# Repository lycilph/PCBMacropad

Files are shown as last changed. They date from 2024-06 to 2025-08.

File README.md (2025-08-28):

# PCBMacropad

Arduino pro micro pinout
* https://learn.sparkfun.com/tutorials/pro-micro--fio-v3-hookup-guide/hardware-overview-pro-micro
 
Kicad resources (for keyboards)
* https://github.com/joe-scotto/scottokeebs/tree/main/Extras/ScottoKicad
* https://github.com/ebastler/marbastlib

Tap drill chart (for self tapping screws into pla)
* https://mae.ufl.edu/designlab/Lab%20Assignments/EML2322L%20Tap%20Drill%20Chart.pdf
* From here: https://www.reddit.com/r/3dprinter/comments/fnlmps/hole_size_for_selftapping_screws/

Keycaps
* https://www.printables.com/model/109679-cherry-mx-low-profile-keycap
* https://www.thingiverse.com/thing:4186055
* https://www.printables.com/model/405230-blank-xda-keycap-mx-compatible
* https://www.printables.com/model/397962-blank-xda-profile-keycaps?ref=makerluis.com

Arduino simulator
* https://wokwi.com/projects/new/arduino-uno
* https://app.cirkitdesigner.com/

Idea for v2:
* https://github.com/dekuNukem/duckyPad-Pro

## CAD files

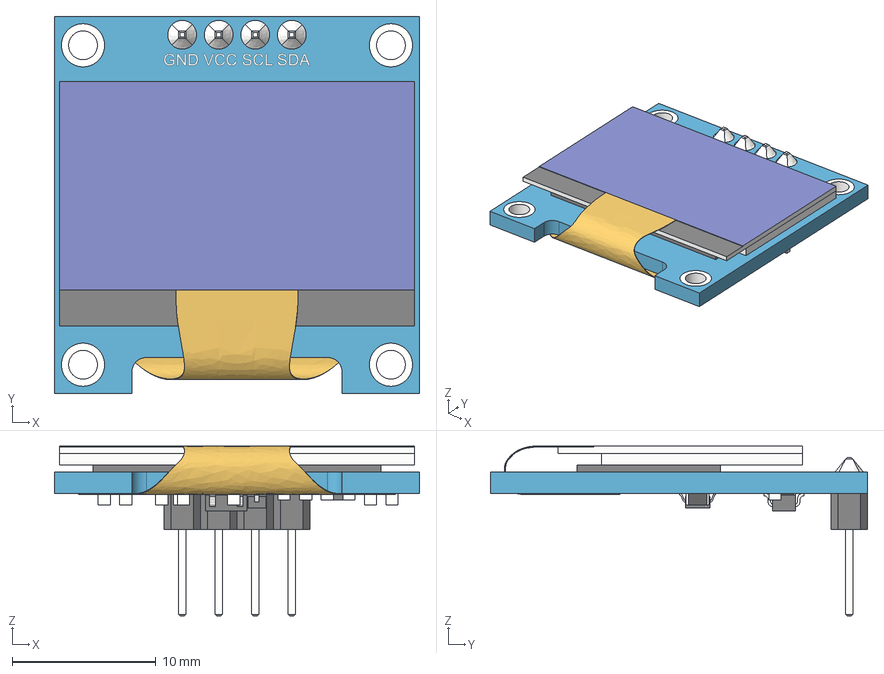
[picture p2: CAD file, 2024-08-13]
pcb_macropad/3dmodels/SSD1306_OLED_Display(128x64).step
25.4 x 26.2 x 11.8 mm
board
screen
pin_header
soldering
smd_capacitor
smd_capacitor (1)
914_smd_resistor
472_smd_resistor x 3
t4_smd_diode
smd_capacitor (2)
smd_capacitor (3)
smd_capacitor (4)
smd_capacitor (5)
smd_capacitor (6)
472_smd_resistor (1)
SOT-23_XC6206 v3
smd_capacitor (7)
flat_cable

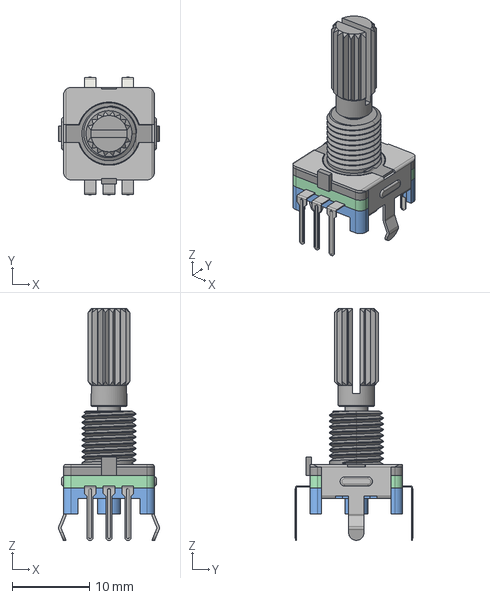
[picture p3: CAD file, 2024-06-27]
pcb_macropad/3dmodels/EC11_Rotary_Encoder_Switched.step
13.1 x 15.3 x 30.1 mm

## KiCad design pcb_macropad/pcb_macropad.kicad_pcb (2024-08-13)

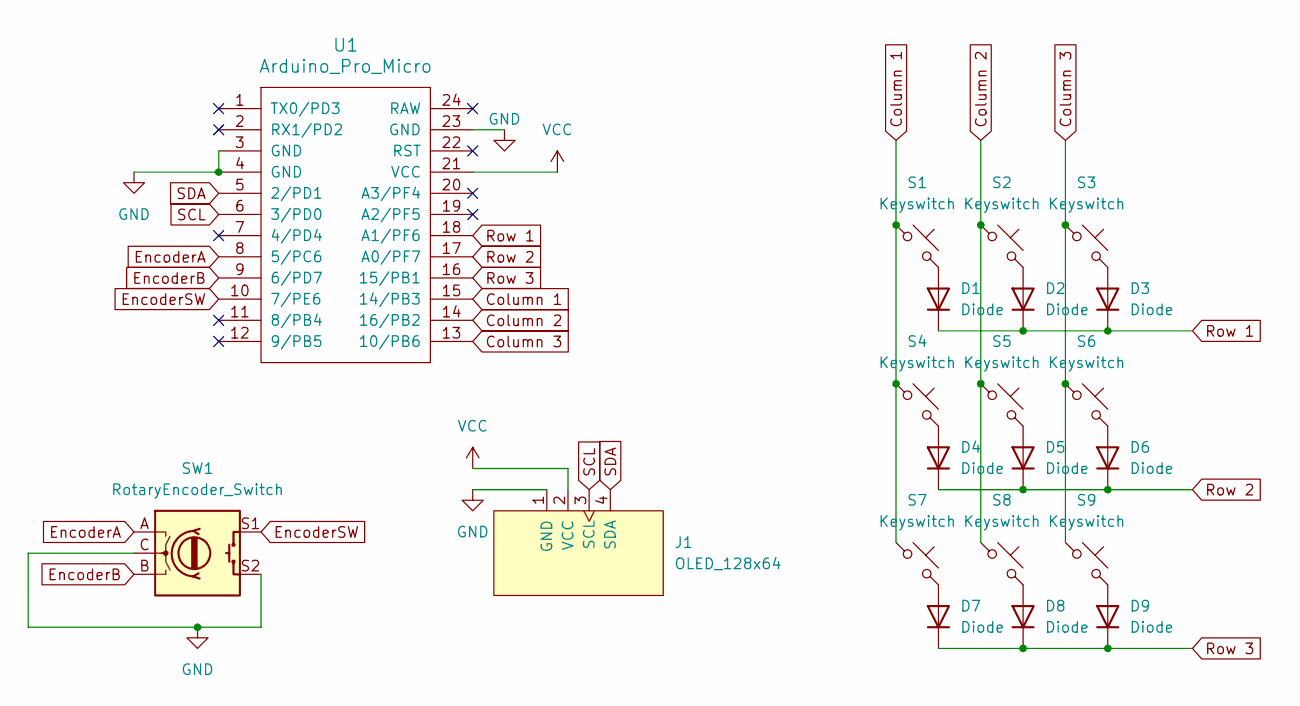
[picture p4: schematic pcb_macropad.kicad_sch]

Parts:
D1, D2, D3, D4, D5, D6, D7, D8, D9: Diode; Diode_DO-35
J1: OLED_128x64; 128x64OLED
S1, S2, S3, S4, S5, S6, S7, S8, S9: Keyswitch; MX_PCB_1.00u
SW1: RotaryEncoder_Switch; RotaryEncoder_Alps_EC11E-Switch_Vertical_H20mm
U1: Arduino_Pro_Micro

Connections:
Column 1: S1.1, S4.1, S7.1, U1.15 (14/PB3)
Column 2: S2.1, S5.1, S8.1, U1.14 (16/PB2)
Column 3: S3.1, S6.1, S9.1, U1.13 (10/PB6)
EncoderA: SW1.A, U1.8 (5/PC6)
EncoderB: SW1.B, U1.9 (6/PD7)
EncoderSW: SW1.S1, U1.10 (7/PE6)
GND: J1.1 (GND), SW1.C, SW1.S2, U1.3 (GND), U1.4 (GND), U1.23 (GND)
unnamed: D1.2 (A), S1.2
unnamed: D2.2 (A), S2.2
unnamed: D3.2 (A), S3.2
unnamed: D4.2 (A), S4.2
unnamed: D5.2 (A), S5.2
unnamed: D6.2 (A), S6.2
unnamed: D7.2 (A), S7.2
unnamed: D8.2 (A), S8.2
unnamed: D9.2 (A), S9.2
Row 1: D1.1 (K), D2.1 (K), D3.1 (K), U1.18 (A1/PF6)
Row 2: D4.1 (K), D5.1 (K), D6.1 (K), U1.17 (A0/PF7)
Row 3: D7.1 (K), D8.1 (K), D9.1 (K), U1.16 (15/PB1)
SCL: J1.3 (SCL), U1.6 (3/PD0)
SDA: J1.4 (SDA), U1.5 (2/PD1)
VCC: J1.2 (VCC), U1.21 (VCC)

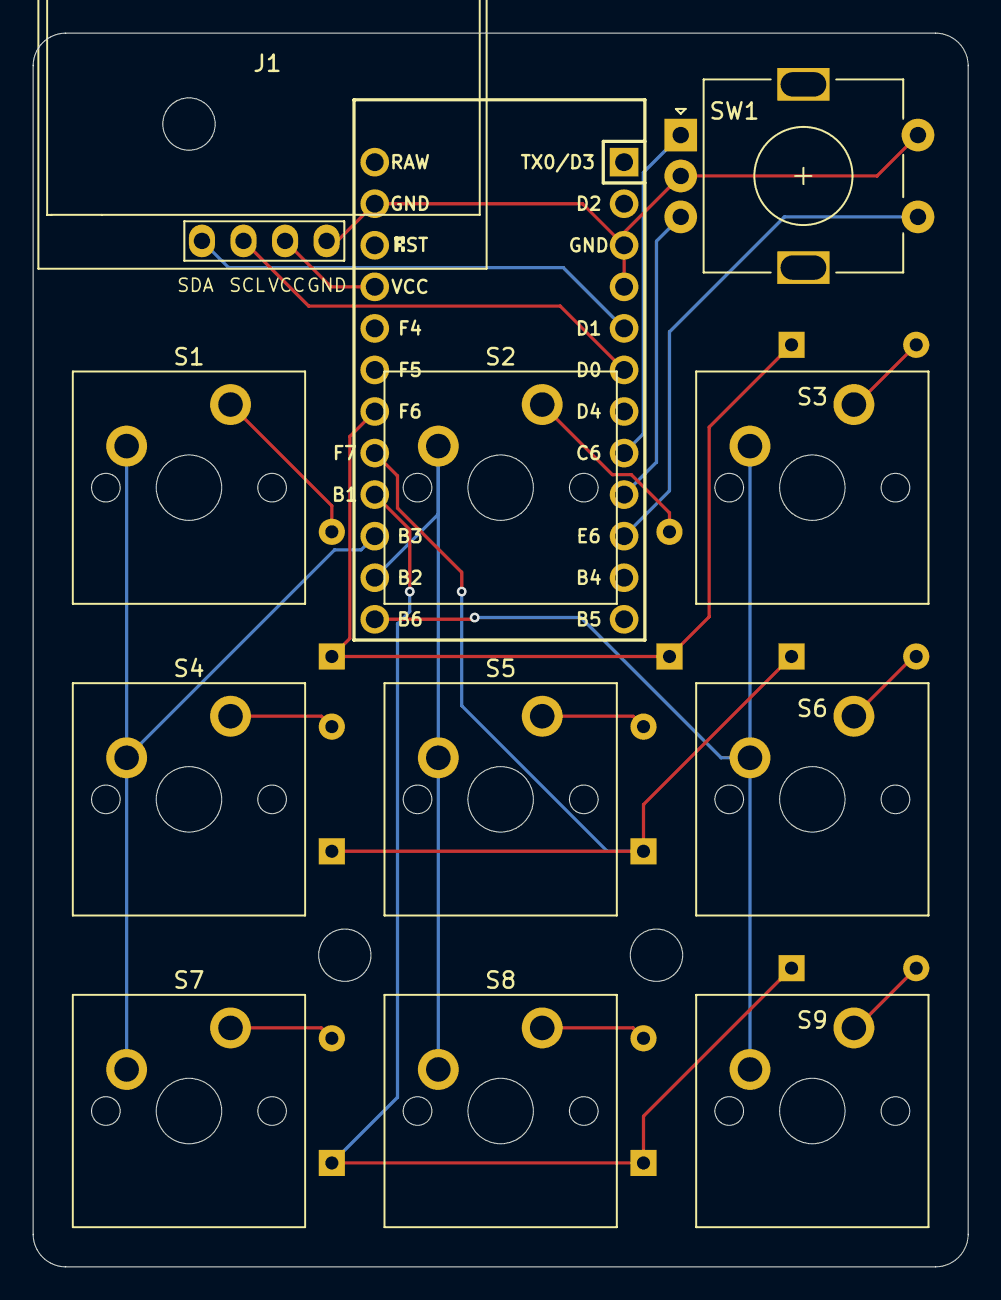
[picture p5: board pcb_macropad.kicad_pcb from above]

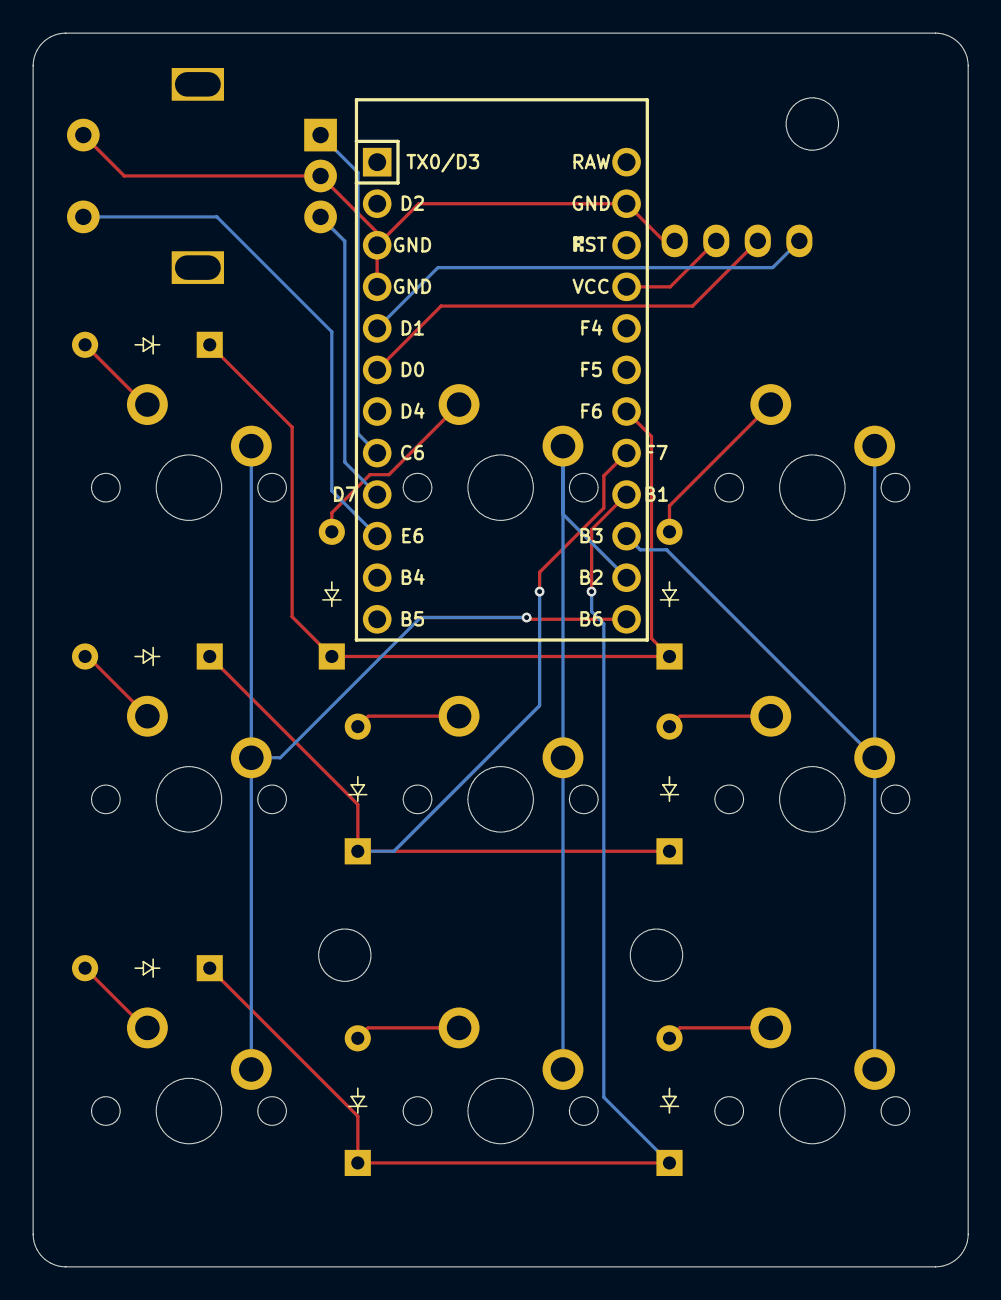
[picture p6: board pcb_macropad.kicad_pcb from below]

Board: 2 copper layers, 57.1 x 75.4 mm, 21 parts (10 on the bottom side), 22 nets.

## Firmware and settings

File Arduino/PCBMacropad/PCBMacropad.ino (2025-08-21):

#include <EncoderButton.h>
#include <LowPower.h>

#include "Keymap.h"
#include "ConfigManager.h"
#include "Macropad.h"
#include "config.h"
#include "CommunicationManager.h"

// U8G2_SSD1306_128X64_NONAME_1_HW_I2C display(U8G2_R2, /* reset=*/ U8X8_PIN_NONE);
#define I2C_ADDRESS 0x3C
SSD1306AsciiAvrI2c display;

// Rotary Encoder setup
const int buttonPin = 7;
const int encoderPin1 = 6;
const int encoderPin2 = 5;
EncoderButton encoderButton(encoderPin1, encoderPin2, buttonPin);

// Keypad stuff
const byte ROWS = 3; // 3 rows
const byte COLS = 3; // 3 columns
char keys[ROWS][COLS] = {
  {'1','4','7'},
  {'2','5','8'},
  {'3','6','9'},
};
byte rowPins[ROWS] = {19, 18, 15}; //connect to the row pinouts of the keypad
byte colPins[COLS] = {14, 16, 10}; //connect to the column pinouts of the keypad
Keypad keypad = Keypad( makeKeymap(keys), colPins, rowPins, ROWS, COLS );

// --- Global Objects ---
Layer allLayers[NUM_LAYERS];
ConfigManager configManager;
Macropad macropad(allLayers, &keypad, &display);
CommunicationManager communicationManager(allLayers, &configManager);

bool hasSlept = false;

void setup() {
  #ifdef ENABLE_SERIAL
    Serial.begin(9600);
    // Wait a moment for serial to connect if needed
    while (!Serial); 
  #endif
  
  #ifdef ENABLE_FREERAM_CHECK
    Serial.print(F("Free SRAM: "));
    Serial.println(freeMemory());
  #endif

  // Start the U8g2 library. This also initializes the I2C communication.
  display.begin(&Adafruit128x64, I2C_ADDRESS);
  displayStart();
  
  // Setup for encoder button
  encoderButton.setEncoderHandler(onEncoderEvent);
  encoderButton.setClickHandler(onEncoderClick);
  encoderButton.setLongPressHandler(onEncoderLongClick);

  configManager.begin();
  configManager.loadConfig(allLayers);
  delay(1000);
  
  macropad.begin();

  communicationManager.begin();

  #ifdef ENABLE_FREERAM_CHECK
    Serial.print(F("Free SRAM: "));
    Serial.println(freeMemory());
  #endif
  
  DEBUG_PRINTLN(F("Macropad Initialized"));
  DEBUG_PRINTLN(F("Send 'd' to dump config"));
  DEBUG_PRINTLN(F("Send 'p' to print layers"));
  DEBUG_PRINTLN(F("Send 'r' for factory reset"));
  DEBUG_PRINTLN(F("Send 'f' to check ram"));
}

void loop() {
  if (USBDevice.isSuspended())
  {
    display.clear();
    delay(500);

    LowPower.idle(SLEEP_8S, ADC_OFF, TIMER4_OFF, TIMER3_OFF, TIMER1_OFF, TIMER0_OFF, SPI_OFF, USART1_OFF, TWI_OFF, USB_OFF);
    hasSlept = true;
  }

  if (hasSlept && USBDevice.isSuspended() == false)
  {
    hasSlept = false;
    macropad.updateDisplay();
  }

  macropad.update();
  encoderButton.update();
  communicationManager.update();

  #ifdef ENABLE_SERIAL
    handleSerialCommands();
  #endif
}

void displayStart()
{
  display.displayRemap(true); // Rotate display 180 deg
  display.setCursor(30, 4);
  display.setFont(Adafruit5x7);
  display.print("Starting...");
  delay(1000);
}

void onEncoderEvent(EncoderButton& eb) {
  int incr = eb.increment();
  if (incr > 0)
  {
    Consumer.write(MEDIA_VOLUME_DOWN);
  }
  else if (incr < 0)
  {
    Consumer.write(MEDIA_VOLUME_UP);
  }
}

void onEncoderClick(EncoderButton& eb) {
  Consumer.write(MEDIA_PLAY_PAUSE);
}

void onEncoderLongClick(EncoderButton& eb) {
  macropad.switchToNextLayer();
}

#ifdef ENABLE_SERIAL
  void handleSerialCommands() {
    if (Serial.available() > 0) {
      char command = Serial.read();

      #ifdef ENABLE_FREERAM_CHECK
        Serial.print(F("Free SRAM: "));
        Serial.println(freeMemory());
      #endif
      
      if (command == 'd') { // 'd' for Dump
        const size_t configSize = sizeof(Layer) * NUM_LAYERS;
        uint8_t serialBuffer[configSize];
        size_t bytesWritten = configManager.serializeConfig(allLayers, serialBuffer, configSize);

        if (bytesWritten > 0) {
          DEBUG_PRINTLN(F("--- BEGIN CONFIG DUMP ---"));
          DEBUG_PRINT(F("Size of config: ")); DEBUG_PRINTLN(configSize);
          for (size_t i = 0; i < bytesWritten; i++) {
            if (serialBuffer[i] < 0x10) DEBUG_PRINT("0");
            DEBUG_PRINT(serialBuffer[i], HEX);
            DEBUG_PRINT(" ");
          }
          DEBUG_PRINTLN();
          DEBUG_PRINTLN(F("--- END CONFIG DUMP ---"));
        } else {
          DEBUG_PRINTLN(F("Error: Serialization failed."));
        }
      }

      if (command == 'p') { // 'p' for print
        for (int i = 0; i < NUM_LAYERS; i++) {
          DEBUG_PRINT("Layer: "); DEBUG_PRINT(allLayers[i].name); DEBUG_PRINT(" - enabled: "); DEBUG_PRINTLN(allLayers[i].isEnabled);
          for (int j = 0; j < NUM_BUTTONS; j++) {
            DEBUG_PRINT("Button "); DEBUG_PRINT(j); DEBUG_PRINT(" - Key: "); DEBUG_PRINT(allLayers[i].actions[j].key); DEBUG_PRINT(" - Modifier: "); DEBUG_PRINT(allLayers[i].actions[j].modifier); DEBUG_PRINT(" - Text: "); DEBUG_PRINTLN(allLayers[i].actions[j].text);
          }
        }
      }
      
      if (command == 'r') { // 'r' for Reset
          DEBUG_PRINTLN(F("Performing factory reset..."));
          configManager.factoryReset(allLayers);
          configManager.saveConfig(allLayers);
          delay(500);
          macropad.updateDisplay();
          DEBUG_PRINTLN(F("Reset complete"));
      }
    }
  }
#endif

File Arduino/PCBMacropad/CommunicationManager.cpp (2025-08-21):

#include <avr/wdt.h>

#include "CommunicationManager.h"
#include "config.h"

CommunicationManager::CommunicationManager(Layer* layerData, ConfigManager *cfgMgr)
  : layers(layerData), configManager(cfgMgr) {}

void CommunicationManager::begin() {
  RawHID.begin(rawhidData, sizeof(rawhidData));
}

void CommunicationManager::update() {
  if (RawHID.available() > 0) {
    #ifdef ENABLE_FREERAM_CHECK
      Serial.print(F("Free SRAM: "));
      Serial.println(freeMemory());
    #endif

    // Read the incoming report into our packet buffer
    memset(packetBuffer, 0, sizeof(packetBuffer));
    RawHID.readBytes(packetBuffer, RAWHID_RX_SIZE);
    int command = packetBuffer[0];

    if (command == CMD_PC_GET_CONFIG) {
      handleGetConfig();
    } else if (command == CMD_PC_SET_CONFIG) {
      handleSetConfig();
    }  else if (command == CMD_PC_CONFIG_DATA) {
      handleConfigData();
    }  else if (command == CMD_PC_RESET_CONFIG) {
      handleResetConfig();
    }
    // Add a command to reset the macropad
    // Should call the factoryReset in the config manager class (and save the reset config to eeprom)

    #ifdef ENABLE_FREERAM_CHECK
      Serial.print(F("Free SRAM: "));
      Serial.println(freeMemory());
    #endif
  }
}

void CommunicationManager::handleGetConfig() {
  const uint8_t* dataPtr = (const uint8_t*)layers;
  uint16_t bytesSent = 0;
  size_t bytesRemaining = CONFIG_DATA_SIZE; // Should be 282

  // --- Send START_RESPONSE Packet ---
  memset(packetBuffer, 0, sizeof(packetBuffer)); // Initialize to all zeros
  packetBuffer[0] = CMD_ARDUINO_SEND_CONFIG; // Command byte
  packetBuffer[1] = (uint8_t)(CONFIG_DATA_SIZE & 0xFF); // Total size (low byte)
  packetBuffer[2] = (uint8_t)((CONFIG_DATA_SIZE >> 8) & 0xFF); // Total size (high byte)
  
  int firstChunkSize = RAW_HID_PAYLOAD_SIZE - PROTOCOL_HEADER_SIZE;
  memcpy(&packetBuffer[3], dataPtr, firstChunkSize);
  RawHID.write(packetBuffer, RAW_HID_PAYLOAD_SIZE);
  bytesSent += firstChunkSize;

  DEBUG_PRINTLN("First packet sent");

  delay(5); // Crucial delay for the PC to process the packet

  // --- Send RESPONSE_DATA_PACKETs ---
  while (bytesSent < bytesRemaining) {
    memset(packetBuffer, 0, sizeof(packetBuffer)); // Initialize next data packet to all zeros
    packetBuffer[0] = CMD_ARDUINO_CONFIG_DATA; // Command byte set to config data

    int chunkSize = min(RAW_HID_PAYLOAD_SIZE - 1, CONFIG_DATA_SIZE - bytesSent);
    memcpy(&packetBuffer[1], &dataPtr[bytesSent], chunkSize);
    
    RawHID.write(packetBuffer, RAW_HID_PAYLOAD_SIZE);
    bytesSent += chunkSize;

    DEBUG_PRINTLN("Data packet sent");

    delay(5); // Crucial delay for the PC to process the packet
  }
}

void CommunicationManager::handleSetConfig() {
  bytesReceived = 0;
  totalDataSize = packetBuffer[1] | (packetBuffer[2] << 8);

  if (totalDataSize > MAX_BUFFER_SIZE) {
    DEBUG_PRINTLN("Error: Requested transfer size is too large.");
    totalDataSize = 0;
    return;
  }

  DEBUG_PRINT("Received START command. Expecting ");
  DEBUG_PRINT(totalDataSize);
  DEBUG_PRINTLN(" bytes.");

  int dataLength = RAW_HID_PAYLOAD_SIZE - PROTOCOL_HEADER_SIZE;
  memcpy(&configDataBuffer[bytesReceived], &packetBuffer[3], dataLength);
  bytesReceived += dataLength;
}

void CommunicationManager::handleConfigData() {
  int dataLength = RAW_HID_PAYLOAD_SIZE - 1; // Cmd
  memcpy(&configDataBuffer[bytesReceived], &packetBuffer[1], dataLength);
  bytesReceived += dataLength;

  DEBUG_PRINTLN("Received data packet");

  if (bytesReceived >= totalDataSize) {
    DEBUG_PRINTLN("\n--- PC->Arduino Transfer Complete! ---");

    memcpy(layers, configDataBuffer, CONFIG_DATA_SIZE);
    configManager->saveConfig(layers);

    bytesReceived = 0;
    totalDataSize = 0;
    DEBUG_PRINTLN("\nWaiting for next command.");

    resetArduino();
  }
}

void CommunicationManager::handleResetConfig() {
  configManager->factoryReset(layers);
  configManager->saveConfig(layers);
  delay(1000);

  resetArduino();
}

void CommunicationManager::resetArduino() {
  wdt_disable();
  wdt_enable(WDTO_15MS);
  while (1) {}
}

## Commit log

2024-06-27 PCB draft done
    [EC11_Rotary_Encoder_Switched.step, pcb_macropad.kicad_pcb, pcb_macropad.kicad_sch]
2024-08-19 Add burn in protection for the oled
    [PCBMacropad.ino]
2025-07-08 Making script compilation threaded
2025-07-08 Working on the configuration of the macropad buttons
2025-07-11 Working on the arduino v2 sketch
2025-07-12 Updating the arduino sketch
2025-07-16 Updating the arduino sketch and starting the implementation in the configurator app
2025-07-17 Running out of memory/ram on arduino, changing to ssd1306ascii
2025-07-17 Saving and loading on the arduino is now fixed and the first communication with the macropad is working
    [CommunicationManager.cpp]
2025-08-09 Added a command to "factory"-reset the macropad
    [CommunicationManager.cpp]
2025-08-11 Cleaning up (removed test projects in both visual studio and arduino)
2025-08-15 Add option to run on windows startup. Also fixed oled invert functionality on macropad
    [PCBMacropad.ino]
2025-08-21 Cleaning up code, and added a reset of the arduino, when a new configuration is uploaded
    [CommunicationManager.cpp]
2025-08-21 Startup message on arduino is now displaying correctly
    [PCBMacropad.ino]
2025-08-21 Added a couple of functions to the scripting host
2025-08-26 Added functionality to change sound device from scripts
